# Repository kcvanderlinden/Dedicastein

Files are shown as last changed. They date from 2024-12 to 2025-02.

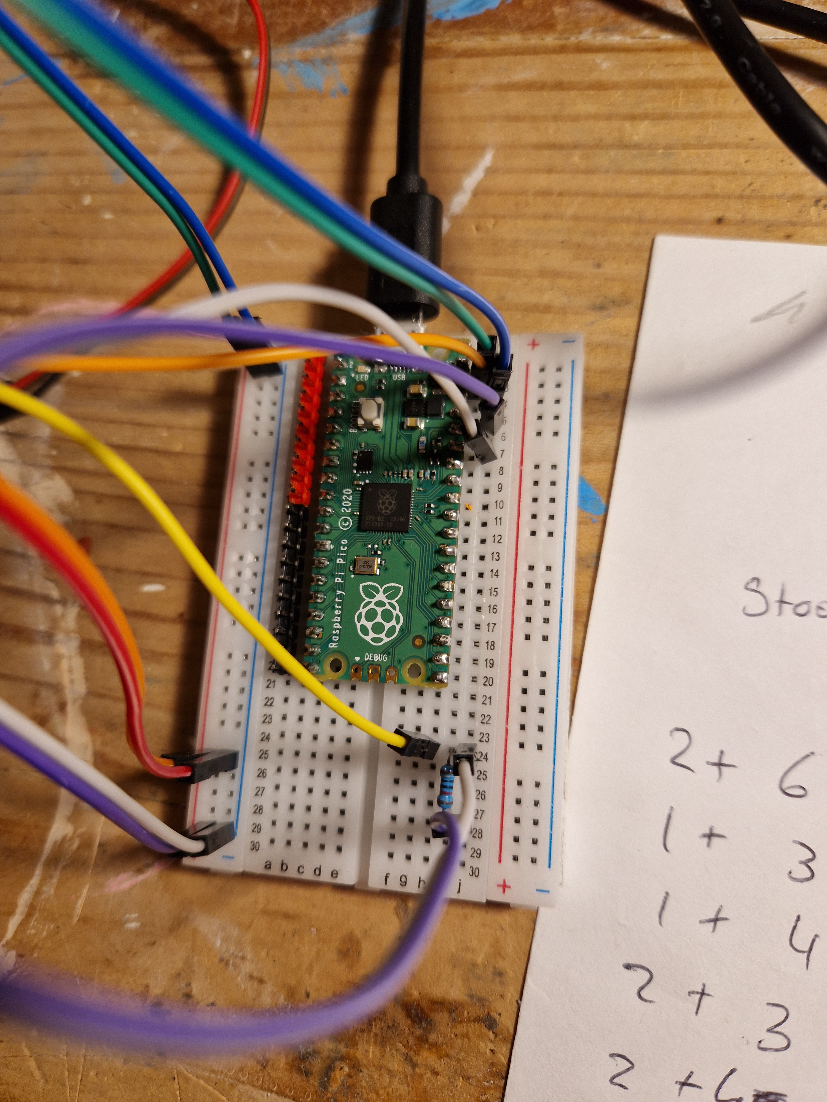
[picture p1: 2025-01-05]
Pictures/Termistor reading.jpg

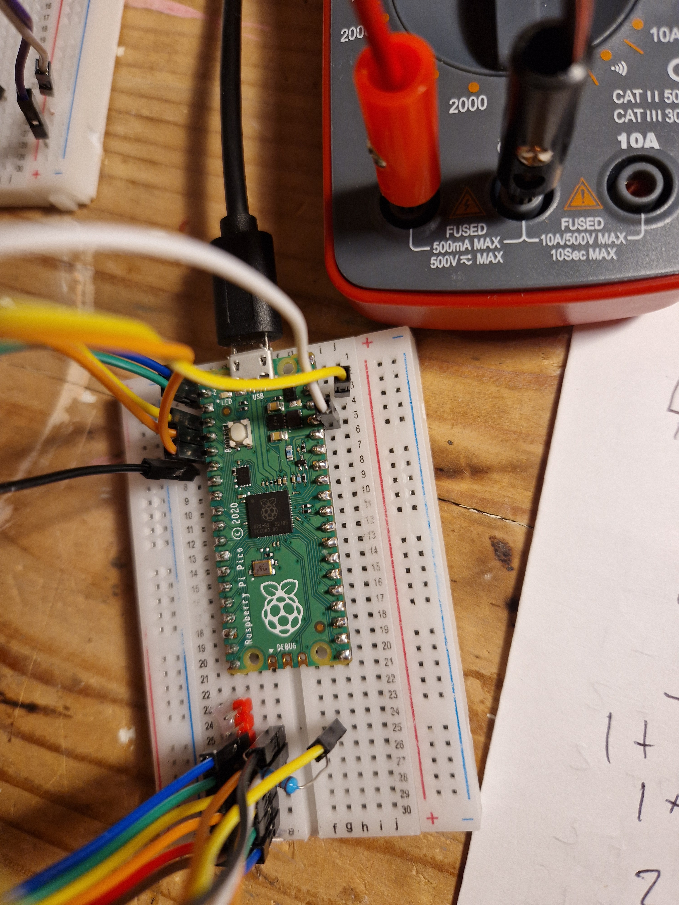
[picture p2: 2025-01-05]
Pictures/Front-buttons.jpg

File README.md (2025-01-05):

A espresso machine can't be that complicated, can it?

# WARNING
This is an ongoing project which has not been fully tested. (re) Use at your own risk.

# AIM
replacing the board of a Delonghi Dedica EC685 with a Raspberry pico.

# TRAIN-OF-THOUGHT
- The GAGGUINO project designed for GAGGIA CLASSIC is a project that makes the espresso machine smart by adding some sensors and controllers. 
- A Dedica is not so different from a GAGGIA CLASSIC: it uses the same pump and uses a simalair heating method.
- An espresso machine in its core is quite simple, such as a Flair. Water needs to heat to a certain point and the pump needs to be powered.
- The heating block and the pump are both 230v.
- Arduino and Pico are designed to control switches and read sensors.
- I need a challenge for in this afwull winter time.
- Being able to add extra sensors and controllers (such as an AC dimmer), enables for more espresso profiling.
- Thinkering with stuff is huge fun.

# CHECKLIST
- [x] Reading the temprature with the termoster 
- [x] Turning the heating block on and off
- [x] PID temprature control
- [x] Turning the pump on and off
- [x] Pump power control (AC dimmer)
- [ ] Reading the flow sensor
- [ ] Implement the steam wand
- [x] Read the front buttons and control the LEDs

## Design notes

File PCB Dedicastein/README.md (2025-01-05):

These schematics are of an untested prototype. So far I have tested the individual components using a breadboard. This worked using the code. I then created the schematic with KiCad and have printed it. I have yet to buy the parts, create the board and test it. 

Recreate at your own risk as it uses main voltage.

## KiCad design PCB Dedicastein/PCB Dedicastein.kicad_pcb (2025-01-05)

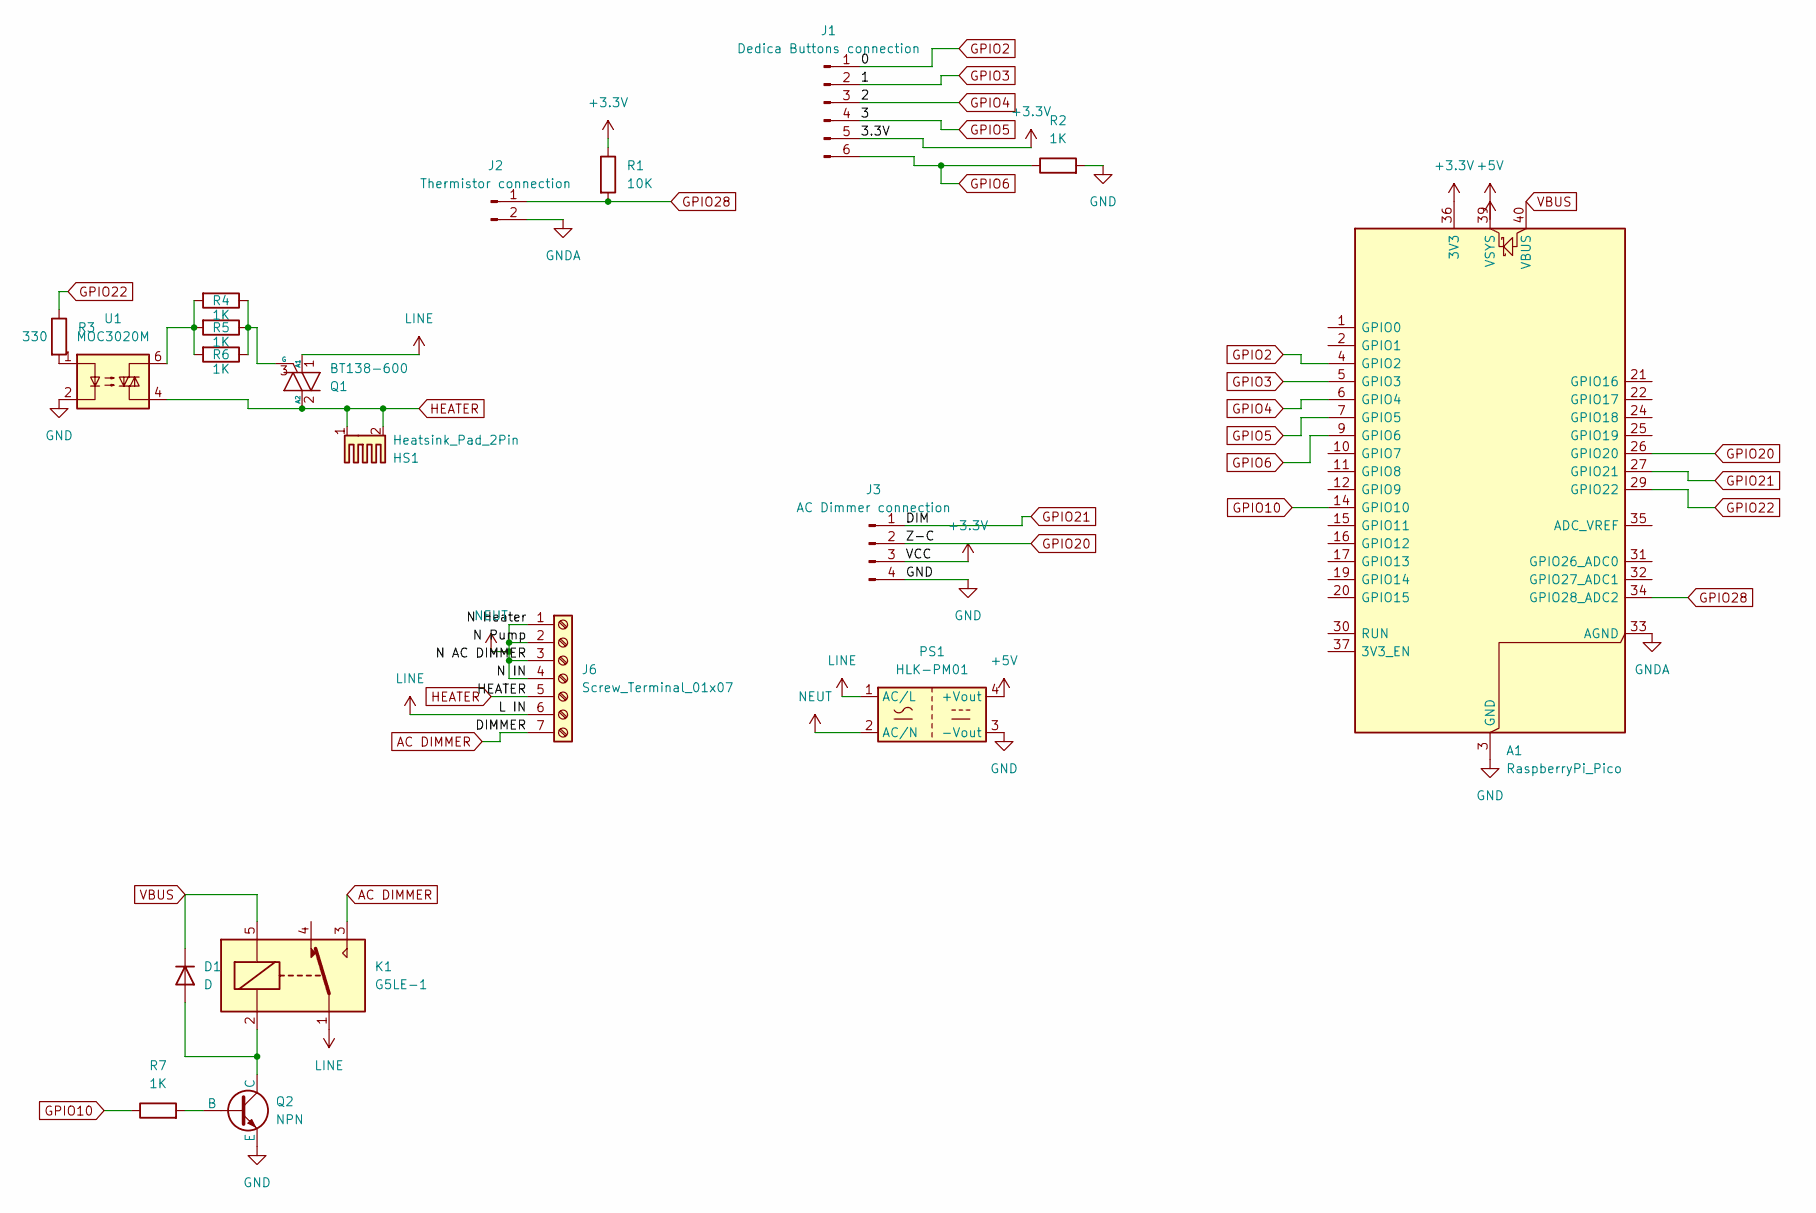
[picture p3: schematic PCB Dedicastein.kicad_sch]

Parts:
A1: RaspberryPi_Pico; RaspberryPi_Pico_Common_THT_MountingHoles
D1: D; D_A-405_P7.62mm_Horizontal
HS1: Heatsink_Pad_2Pin; Heatsink_Fischer_SK104-STC-STIC_35x13mm_2xDrill2.5mm
J1: Dedica Buttons connection; PinSocket_1x06_P2.54mm_Vertical
J2: Thermistor connection; PinSocket_1x02_P2.54mm_Vertical
J3: AC Dimmer connection; PinSocket_1x04_P2.54mm_Vertical
J6: Screw_Terminal_01x07; Altech_AK100_1x07_P5.00mm
K1: G5LE-1; Relay_SPDT_Omron-G5LE-1
PS1: HLK-PM01; Converter_ACDC_Hi-Link_HLK-PMxx
Q1: BT138-600; TO-220-3_Vertical
Q2: NPN; 3-LEADTO-92BULK
R1: 10K; R_Axial_DIN0204_L3.6mm_D1.6mm_P5.08mm_Horizontal
R2, R4, R5, R6, R7: 1K; R_Axial_DIN0204_L3.6mm_D1.6mm_P5.08mm_Horizontal
R3: 330; R_Axial_DIN0204_L3.6mm_D1.6mm_P5.08mm_Horizontal
U1: MOC3020M; DIP762W51P254L851H508Q6N

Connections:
+3.3V: A1.36 (3V3), J1.5, J3.3, R1.1
+5V: A1.39 (VSYS), PS1.4 (+Vout)
AC DIMMER: J6.7, K1.3
GND: A1.3 (GND), A1.8 (GND), A1.13 (GND), A1.18 (GND), A1.23 (GND), A1.28 (GND), A1.38 (GND), J3.4, PS1.3 (-Vout), Q2.3 (E), R2.2, U1.2
GNDA: A1.33 (AGND), J2.2
GPIO2: A1.4 (GPIO2), J1.1
GPIO3: A1.5 (GPIO3), J1.2
GPIO4: A1.6 (GPIO4), J1.3
GPIO5: A1.7 (GPIO5), J1.4
GPIO6: A1.9 (GPIO6), J1.6, R2.1
GPIO10: A1.14 (GPIO10), R7.1
GPIO20: A1.26 (GPIO20), J3.2
GPIO21: A1.27 (GPIO21), J3.1
GPIO22: A1.29 (GPIO22), R3.1
GPIO28: A1.34 (GPIO28_ADC2), J2.1, R1.2
HEATER: HS1.1, HS1.2, J6.5, Q1.2 (A2), U1.4
LINE: J6.6, K1.1, PS1.1 (AC/L), Q1.1 (A1)
NEUT: J6.1, J6.2, J6.3, J6.4, PS1.2 (AC/N)
unnamed: D1.2 (A), K1.2, Q2.1 (C)
unnamed: Q1.3 (G), R4.1, R5.1, R6.1
unnamed: Q2.2 (B), R7.2
unnamed: R3.2, U1.1
unnamed: R4.2, R5.2, R6.2, U1.6
VBUS: A1.40 (VBUS), D1.1 (K), K1.5

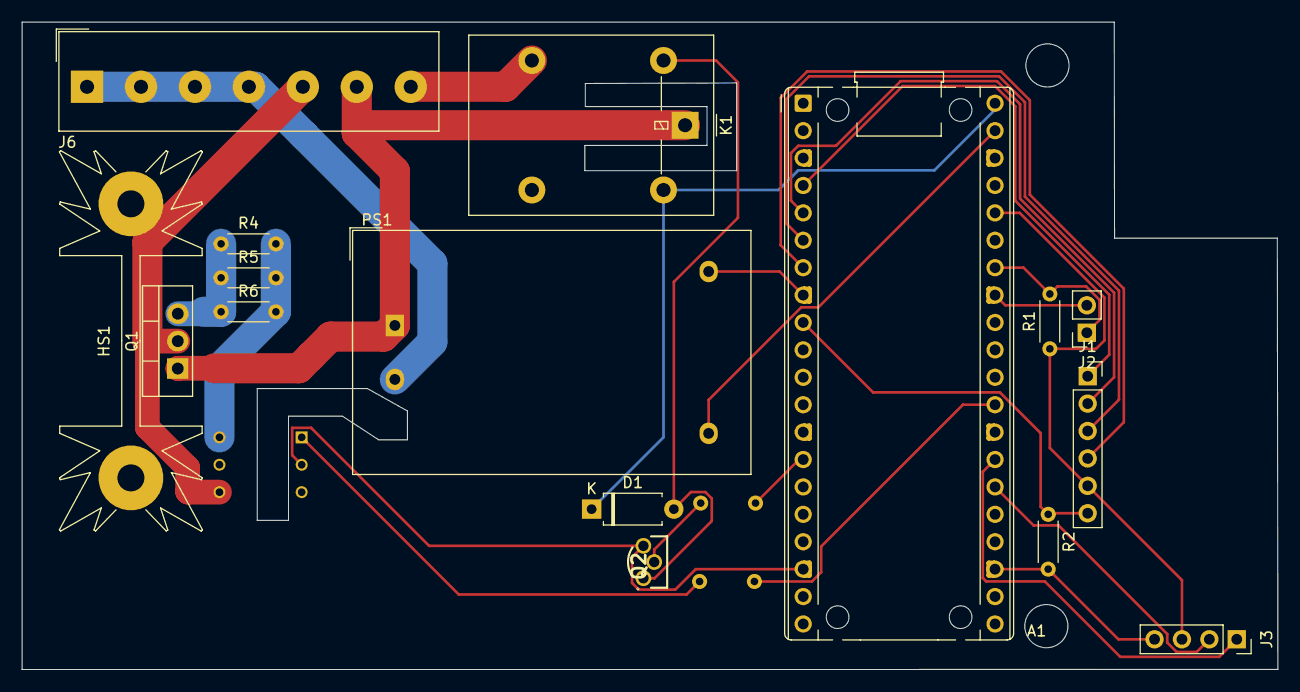
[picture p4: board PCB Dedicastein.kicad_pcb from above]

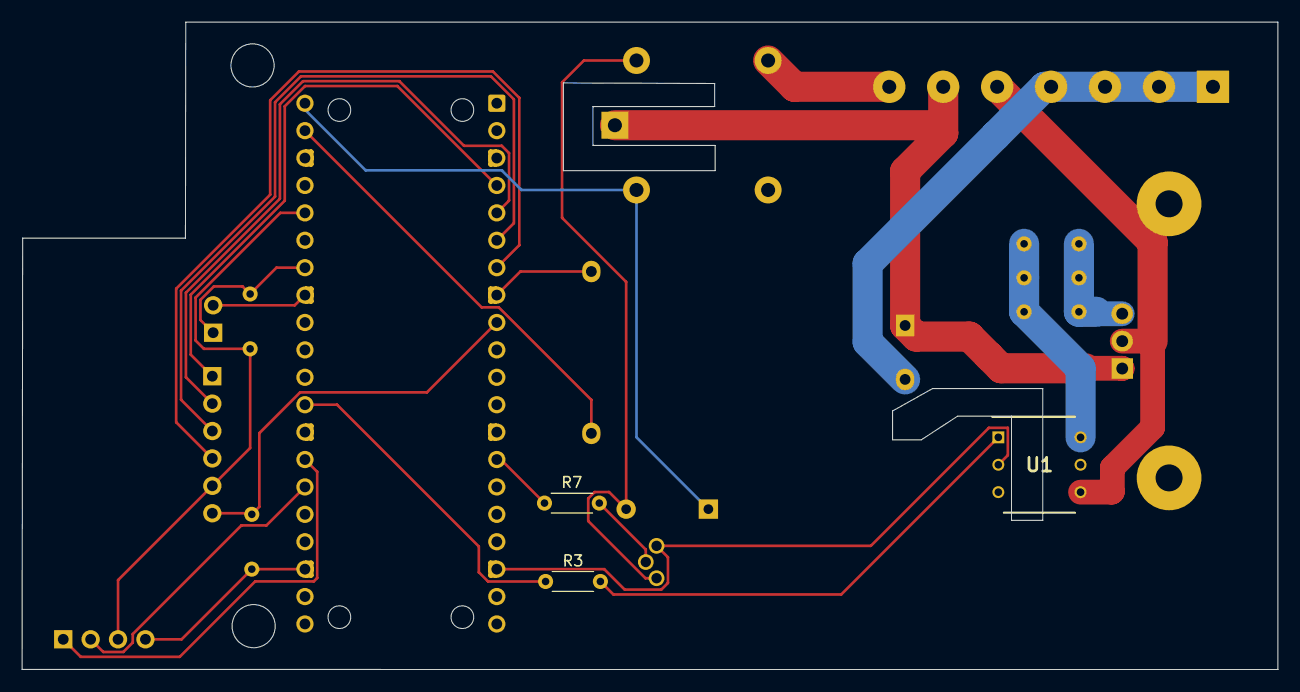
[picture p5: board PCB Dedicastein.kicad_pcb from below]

Board: 2 copper layers, 116.4 x 60.0 mm, 19 parts (3 on the bottom side), 24 nets.

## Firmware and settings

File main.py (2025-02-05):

from thermoster import read_temperature
from machine import Pin, PWM
from PID import PID
import asyncio
import time
from dedicamodules import handle_relay_by_buttons

# Constants
TARGET_TEMPERATURE = 80.0 # Desired temperature in Celsius
PWM_FREQUENCY = 50         # PWM frequency in Hz
MAX_DUTY_CYCLE = 65535     # Maximum duty cycle for Pico's PWM (16-bit resolution)

# Initialize the SSR pin and PWM
ssr_pin = Pin(22, Pin.OUT)  # Replace with your SSR GPIO pin number
pwm_ssr = PWM(ssr_pin)
pwm_ssr.freq(PWM_FREQUENCY)

pid = PID(600, .5, 5, setpoint=TARGET_TEMPERATURE)
pid.output_limits = (0, 65535)

# time
last_time = time.ticks_ms()

def get_temperature():
    return read_temperature()

while True:
    # Run the main event loop
    asyncio.run(handle_relay_by_buttons())
    current_time = time.ticks_ms()
    current_temp = get_temperature()
    power = pid(current_temp)
    duty_cycle = max(0, min(MAX_DUTY_CYCLE, int(power)))
    pwm_ssr.duty_u16(duty_cycle)
    if (current_time - last_time) / 1000 > 1: # log every second
        
        last_time = current_time
        print(f"Current Temperature: {current_temp:.2f}°C")
        print(power)

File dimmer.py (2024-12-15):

from machine import Timer, Pin
from micropython import alloc_emergency_exception_buf
from math import acos, pi

# only tested with a lamp
class Dimmer:
    def __init__(self, pwm_pin, zc_pin, fpulse = 4000):
        alloc_emergency_exception_buf(100)
        self._cnt    = 0
        self._freq   = 140
        self._timer  = Timer()
        self.triacFiringPin = Pin(pwm_pin, Pin.OUT, value=0)
        self._fpulse = fpulse
        self._ppulse = 100.0 / fpulse + 0.11
        self.zeroCrossoverPin = Pin(zc_pin, Pin.IN, Pin.PULL_DOWN)
        self._val    = 1
        self.zeroCrossoverPin.irq(trigger=Pin.IRQ_RISING, handler=self.ZeroCrossover)

    def triacpulse(self, a):
        global dummy
        self.triacFiringPin.high()
        for x in range (50): pass
        self.triacFiringPin.low()
        
    def ZeroCrossover(self, arg):
        self.triacFiringPin.low()
        self._timer.init(freq=self._freq,mode=Timer.ONE_SHOT,callback=self.triacpulse)
    
    @property
    def value(self):
        return self._val
    
    
    @value.setter
    def value(self, p):
        p = p/100
        self._val = p
        p = min(1, max(0, p))
        p = acos(1 - p * 2) / pi
                
        if p < 0.15 :
            self._freq = 20
        elif p > 0.99:
            self._freq = 0
        else:
            self._freq = int(100 / (1 - p))
        print(f"value set as {self._freq}")
        self.zeroCrossoverPin.irq(trigger=Pin.IRQ_RISING, handler=self.ZeroCrossover)
        return self._val

'''dimmer = Dimmer(21, 20)        
while True:
    dimmer.value = int(input ( "enter number between 1 and 100: " ))'''

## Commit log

2024-12-15 add dimmer, button and PID function
2025-01-05 Add PCB design for new mainboard Dedica
    [PCB Dedicastein.kicad_pcb, PCB Dedicastein.kicad_sch]
2025-01-05 add pictures of some prototype wiring.
2025-02-05 Add asyncio use for handling buttons presses and toggling relay
